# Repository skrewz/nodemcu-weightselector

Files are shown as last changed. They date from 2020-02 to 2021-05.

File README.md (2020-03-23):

# nodemcu-weightselector
A (very) simple (yet somehow overcomplicated) button to select who stepped on a scale.

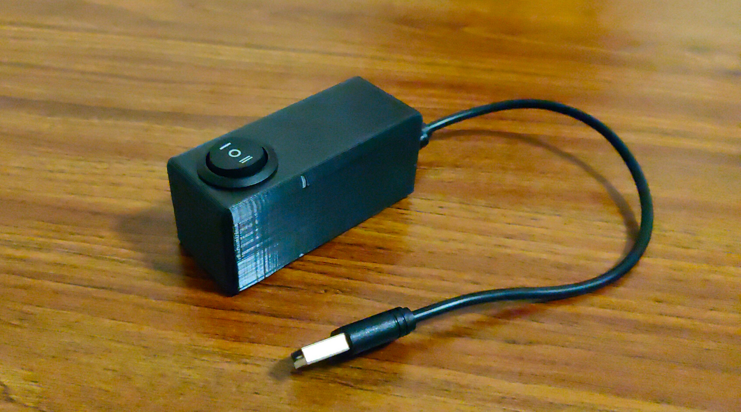
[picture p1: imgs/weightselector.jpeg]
A button. In a case. Weightselector case


# Submodules beware

This repo has submodules, notably [nodemcu-scaffold](https://github.com/skrewz/nodemcu-scaffold), and chained therefrom, [nodemcu-libs](https://github.com/skrewz/nodemcu-libs).

You should thus **clone with git's `--recursive` flag**.

# How does this work?

This is pretty specific to my use case. Two people (cleverly named `user1` and `user2`) have each their side of a flipbutton, and an independent system publishes a raw float value (in kilogrammes) onto the MQTT topic `datainput/bathroom/scale/raw`. In turn, this device's **only goal in life is to interpret this relative to the state of the button, and re-publish accordingly**.

That's a fair bit of work for something so trivial.

On the other side, another MQTT client is picking up on the published (and now labelled) JSON and putting into InfluxDB. I haven't provided the code for that.

# Getting started

## Printing

The OpenSCAD file is under the [openscad folder](openscad/). I've also put in [an STL file](openscad/weightselector_case.stl) for those of you who can't be bothered to start up OpenSCAD.

It's meant to be printed in the orientation of the model. The strips across provide some (but not great) adhesion surface for Blu-Tack'ing this to a wall or something. Dupont cables can (barely) fit inside, so **the whole thing is disassembly-friendly**.

## Building/uploading

This example is fairly self-contained. It ought to be possible to simply run `make upload` and issue a `node.flashreload("lfs.img")` from within the serial console, referring to [nodemcu-scaffold's README](https://github.com/skrewz/nodemcu-scaffold/blob/master/README.md). Of course, it'll fail horribly at connecting to my MQTT setup, etc.

You'll need the [ws2812](https://nodemcu.readthedocs.io/en/master/modules/ws2812/) and [ws2812-effects](https://nodemcu.readthedocs.io/en/master/modules/ws2812-effects/) modules for this demo, too. Those in turn require the [bit](https://nodemcu.readthedocs.io/en/master/modules/bit/) module, if memory serves.

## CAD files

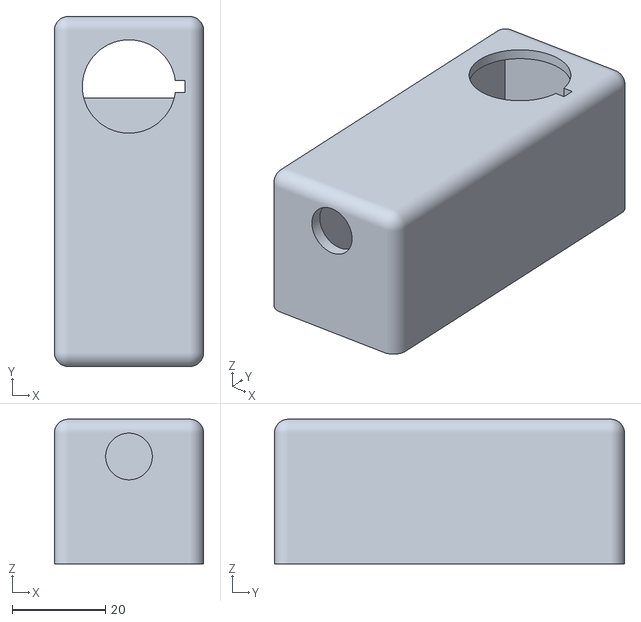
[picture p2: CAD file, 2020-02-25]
openscad/weightselector_case.stl
32.0 x 75.0 x 31.0

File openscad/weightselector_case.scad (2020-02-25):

$fn=90;

cutout_wdh = [27,55,28];
sensorbase_d = 15;
bme680_funnel_wd = [18,25];
bme680_pcb_w = 4;
bme680_pcb_indent = 10;
bme680_pcb_throughhole_wh = [6,6];

pcb_holder_height = 11;

ccs811_pcb_throughhole_whd = [22,8,10];
wall_w = 1.0;

tape_strip_w = 9;

corner_r = 3;

bme680_y_offset = cutout_wdh[1]+sensorbase_d-corner_r-bme680_pcb_w;
ccs811_y_offset = cutout_wdh[1]+sensorbase_d-corner_r-30;

difference()
{
  translate([corner_r,corner_r,0])
  {
  difference()
  {
    minkowski()
    {
      cube([
        cutout_wdh[0]+2*wall_w-corner_r,
        cutout_wdh[1]+sensorbase_d+2*wall_w-corner_r,
        cutout_wdh[2]
        ]);
      //cylinder(r=corner_r,h=1);
      sphere(r=corner_r);
    }
    translate([-500,-500,-1000])
      cube([1000,1000,1000]);
  }
  }

  translate([wall_w+corner_r/2,wall_w+corner_r/2,-2*wall_w])
  {
    difference()
    {
      cube([cutout_wdh[0],cutout_wdh[1]+sensorbase_d,cutout_wdh[2]+corner_r]);
      for (yoff=[
          tape_strip_w,
          //cutout_wdh[1]/2+tape_strip_w,
          //ccs811_y_offset-0.5*ccs811_pcb_throughhole_whd[1],
          cutout_wdh[1]+sensorbase_d-2.5*bme680_pcb_throughhole_wh[1],
          ])
        translate([0,yoff-tape_strip_w,0])
          cube([cutout_wdh[0],tape_strip_w,3*wall_w]);
    }
  }


  translate([
    cutout_wdh[0]/2+wall_w+corner_r/2,
    cutout_wdh[1]+sensorbase_d-10,
    cutout_wdh[2]-ccs811_pcb_throughhole_whd[2]]) {
    rotate([0,0,90])
    translate([-1.3,-12,0])
      cube([2.6,5,30]);
    cylinder(r=10,h=30);
  }

  translate([
    wall_w+corner_r/2+cutout_wdh[0]/2,
    wall_w+corner_r/2+wall_w,
    cutout_wdh[2]-5])
    rotate([90,0,0])
      cylinder(r=5,h=corner_r+2*wall_w);
}

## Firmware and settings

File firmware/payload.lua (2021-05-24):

local M
do
  local self = {
    pin_user1 = 1,
    pin_user2 = 2,
    currently_selected_user = nil,
    tmr_disable = nil,
  }

  -- Owing to https://gist.github.com/marcelstoer/75ba30a4aec56d1b3810
  local debounce = function (func)
      local last = 0
      local delay = 50000 -- 50ms * 1000 as tmr.now() has μs resolution

      return function (...)
          local now = tmr.now()
          local delta = now - last
          if delta < 0 then delta = delta + 2147483647 end; -- proposed because of delta rolling over, https://github.com/hackhitchin/esp8266-co-uk/issues/2
          if delta < delay then return end;

          last = now
          return func(...)
      end
  end


  local colour_effect = function (colour,effect)
    print("colour_effect("..colour..","..effect..")")
    if "red" == colour then
      ws2812_effects.set_color(0,255,0)
    elseif "green" == colour then
      ws2812_effects.set_color(255,0,0)
    elseif "blue" == colour then
      ws2812_effects.set_color(0,0,255)
    elseif "black" == colour then
      ws2812_effects.set_color(0,0,0)
    end

    print("setting mode: "..effect)
    ws2812_effects.set_mode(effect)
    ws2812_effects.start()
  end

  local disable = function ()
    print("disable() invoked")
    colour_effect("black","static")
    self.currently_selected_user = nil
  end

  local button_state_handler = function ()
    if nil ~= self.tmr_disable then
      self.tmr_disable:stop()
    end

    local u1_val = gpio.read(self.pin_user1)
    local u2_val = gpio.read(self.pin_user2)
    print ("button_state_handler, have user1="..u1_val.." user2="..u2_val)

    if 1 == u1_val and 1 == u2_val then
      self.currently_selected_user = nil
      colour_effect("black","static")
    elseif 0 == u1_val then
      self.currently_selected_user = 1
      colour_effect("blue","static")
    elseif 0 == u2_val then
      self.currently_selected_user = 2
      colour_effect("red","static")
    end

    if nil ~= self.currently_selected_user then
      mqttwrap.maybepublish("datainput/bathroom/weightselector/user_selected", "name=user"..tostring(self.currently_selected_user), 0, 0)
    end

    self.tmr_disable:register(300000, tmr.ALARM_SINGLE, disable)
    self.tmr_disable:start()

  end

  local early = function()
    self.tmr_disable = tmr.create()
    ws2812.init(ws2812.MODE_SINGLE)
    self.strip_buffer = ws2812.newBuffer(1, 3)
    ws2812_effects.init(self.strip_buffer)
    ws2812_effects.set_speed(240)
    ws2812_effects.set_brightness(50)
    ws2812_effects.set_color(0,0,0)
    ws2812_effects.set_mode("static")
    ws2812_effects.start()

    gpio.mode(self.pin_user1,gpio.INT,gpio.PULLUP)
    gpio.mode(self.pin_user2,gpio.INT,gpio.PULLUP)
    gpio.trig(self.pin_user1, 'both', debounce(button_state_handler))
    gpio.trig(self.pin_user2, 'both', debounce(button_state_handler))

  end

  local main = function()
    mqttwrap.subscribe("datainput/bathroom/scale/raw",0)
    mqttwrap.subscribe("datainput/bathroom/scale/published",0)

    button_state_handler()

    -- When a "yes, published" message arrives, light up green to indicate
    -- success.
    mqttwrap.handletopic("datainput/bathroom/scale/published", function(topic, data)
      colour_effect("green","static")
      self.tmr_disable:register(600000, tmr.ALARM_SINGLE, disable)
      self.tmr_disable:start()
    end)

    -- A stringified float will arrive on this topic whenever the scale
    -- produces a new weighing.
    mqttwrap.handletopic("datainput/bathroom/scale/raw", function(topic, data)
      rawval = tonumber(data)

      if 1 == self.currently_selected_user then
        name_chosen = "user1"
      elseif 2 == self.currently_selected_user then
        name_chosen = "user2"
      else
        colour_effect("unmatched","random_color")
        self.tmr_disable:register(5000, tmr.ALARM_SINGLE, disable)
        self.tmr_disable:start()
        return
      end
      local tm = rtctime.epoch2cal(rtctime.get())
      buf = string.format('{"ts":"%04d-%02d-%02dT%02d:%02d:%02dZ","type":"weightinput","location": "%s", "device":"%s","name":"%s","weight":%.3f}',
      tm["year"], tm["mon"], tm["day"], tm["hour"], tm["min"], tm["sec"],
      location,
      myname,
      name_chosen,
      rawval)
      print("buf is:"..buf)

      -- make the current color blink:
      colour_effect("unmatched","blink")
      mqttwrap.maybepublish("datainput/bathroom/scale/selected", buf, 0, 0)
    end)
  end

  -- expose
  M = {
    early = early,
    main = main,
  }
end
return M

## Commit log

2020-02-25 README update + OpenSCAD files.
    [weightselector_case.scad, weightselector_case.stl]
2020-10-20 Significantly longer timers
    (It makes sense given the highly asynchronous behaviour of the BLE
    scraping.)
2021-05-24 button_state_handler() can no longer be called from early()
    + simplification of user-output
    [payload.lua]
